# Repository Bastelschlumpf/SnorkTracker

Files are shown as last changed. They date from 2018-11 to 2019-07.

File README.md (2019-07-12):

## SnorkTracker
   **GPS IoT tracker board for scanning gps and environment information and sending them to an MQTT server via GPRS.**
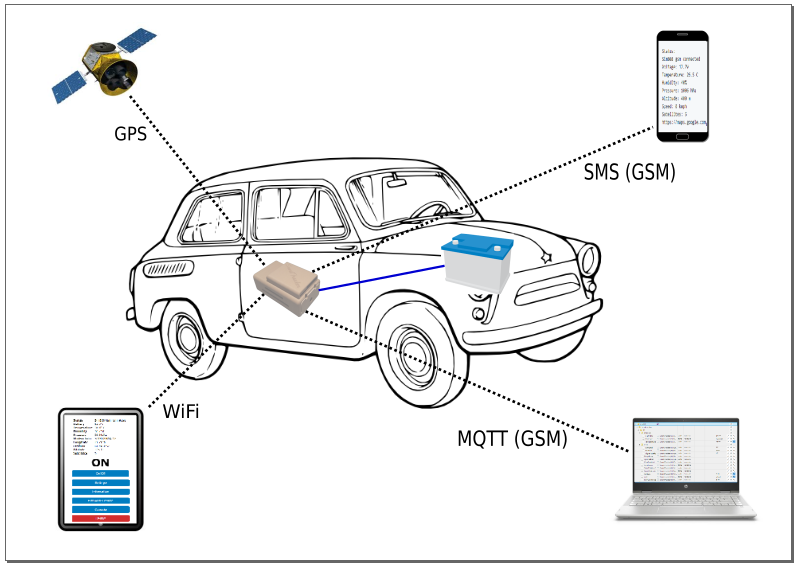
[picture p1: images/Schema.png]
SnorkTracker Schema
   

   **IoBroker map of the collected SnorkTracker sample.  
   (see https://github.com/Bastelschlumpf/SnorkView)**
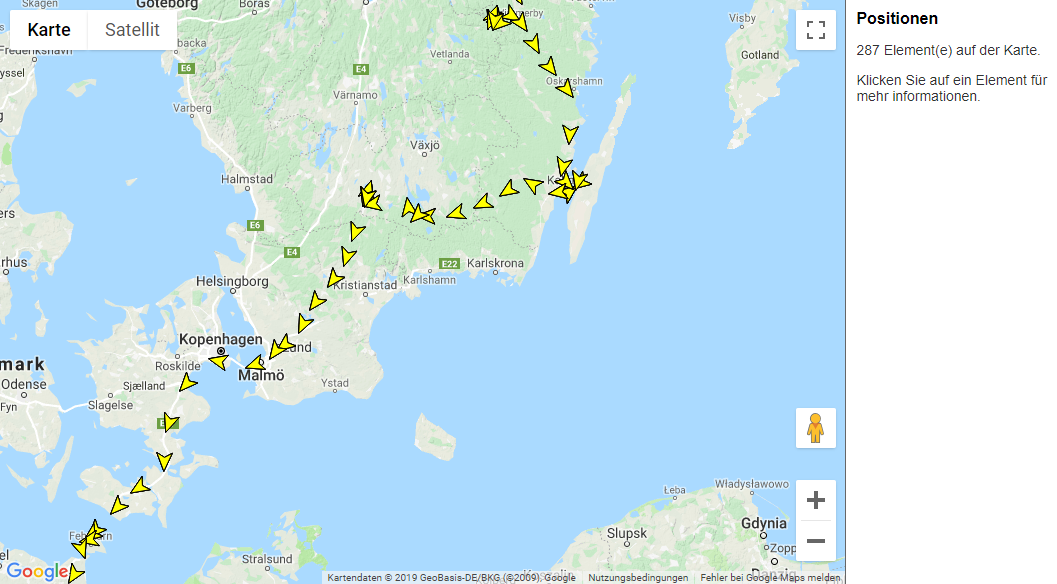
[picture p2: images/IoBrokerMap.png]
SnorkTracker View SnorkTracker Schema
   

   **The hardware**  
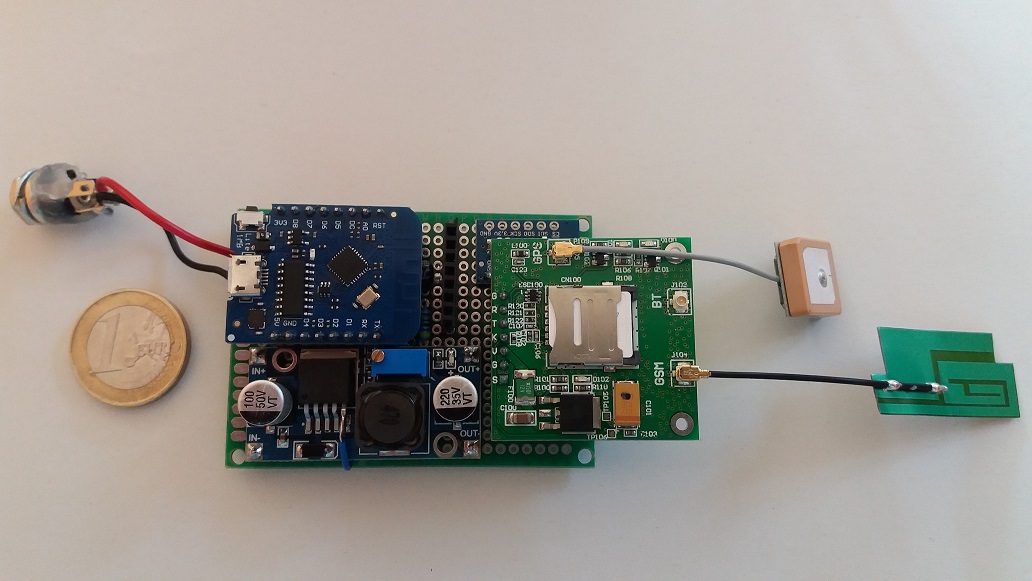
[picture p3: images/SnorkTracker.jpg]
SnorkTracker
   

   **The housing**  
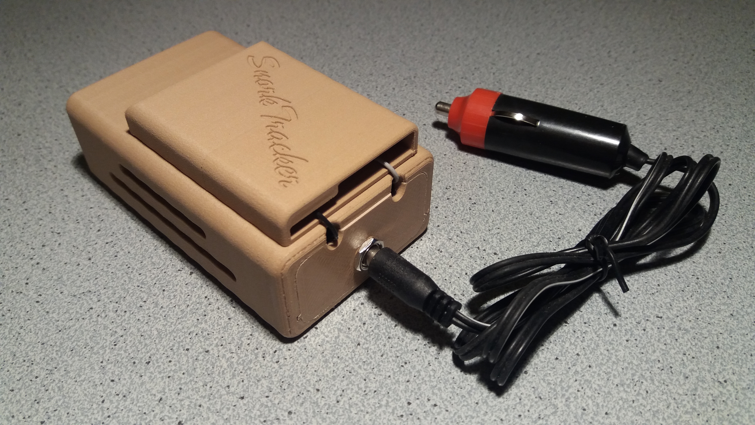
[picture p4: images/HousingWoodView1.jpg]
   

   **The web-interface**  
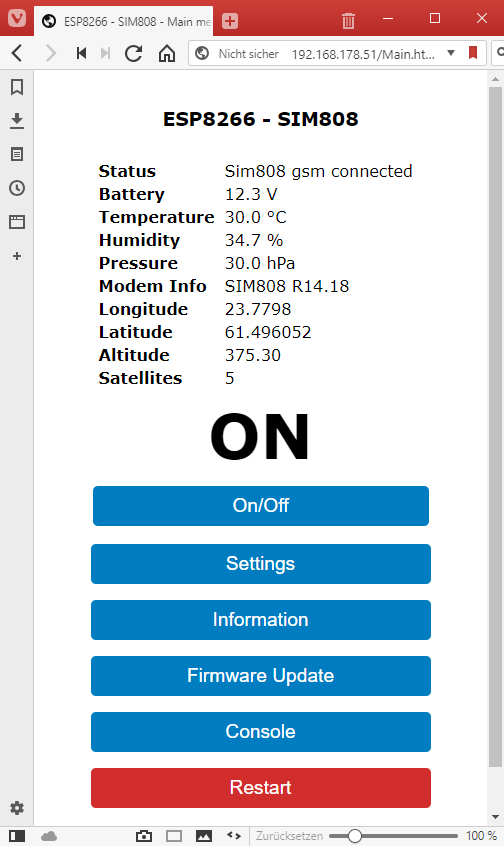
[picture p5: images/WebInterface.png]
Web interface
   

### Description
   The goal of this board is to have an easy-to-use, configurable GPS tracker that passes its data to an MQTT server. 
   It should also be able to scan other environmental data and operate on a 12V power supply with low power consumption 
   over a long period of time.

   The main components of the systems are:
   * A 'Wemos D1 mini lite' to run the software.
   * A BK-808 v2 (SIM808) GPS/GPRS module to communicate with an MQTT server and to send/receive SMS.
   * A BME280 module to scan environmental data.
   * An LM2596 DC-DC converter to supply the GPS/GPRS board.
   * An MCP1703 for the 3.3V Wemos power supply.

   To interact with the board it has an easy-to-use browser interface to show the
   scanned values, configure the system or to debug at runtime via console. 
   It can connect to an existing WiFi or function as an access point.

   The board has a voltage divider to measure the power supply voltage and
   a BME280 sensor to read temperature, humidity and air pressure.

   The module operates with a supply voltage of approx. 6V to 16V. Perfect for a car battery.

   For power saving the supply voltage can be used to decide if the battery is charging or not
   and so the system can be configured to go into deep sleep mode which uses only ~0.3mA.

   With the GSM chip, the system can receive SMS commands to set default values or send current
   information such as GPS or temperature.

   The system estimates the current power consumption in mAh in energy saving mode and when the sim module is on. 

   You can also use the software on a esp8266 chip like the wemos d1 for having a serial console over HTTP if you connect
   to the D5 and D6 pin.

### Disclaimer
   I don't take any responsibility nor liability for using this software nor for the 
   installation or any tips, advice, videos, etc. given by any member of this site or any related site.

### License
   This program is licensed under GPL-3.0

### Source Code
   The easiest way to understand what the program does is to navigate by the main source modules via the Arduino IDE or 
   to explore the source code via
   [**DoxyGen generated documentation**](https://bastelschlumpf.github.io/SnorkTracker).  
   You can update the DoxyGen generated documentation by installing Doxygen (from http://www.doxygen.org) on your machine 
   and run the DoxyGen generation batch **Doxygen.bat** from the main folder.

### User manual of the web interface
  * [Overview of the system settings](docs/Seettings.md)
  * [Switch on or off the system](docs/SwitchOnOff.md)
  * [Using the sms interface](docs/SMS.md)
  * [Display system information](docs/Information.md)
  * [Working with the console](docs/Console.md)
  * [Firmware Update 'over the air'](docs/OTA.md)
  * [Restart the system](docs/Restart.md)

### Prerequisites
   * Arduino IDE
   * ESP8266 Board software
   * ESP8266 file-system up-loader
   * **SnorkTracker** software
   * Parts from the part-list
   * Micro-USB cable
   * Soldering iron kit
   * Multimeter
   * Electronics tools

### Setup Arduino Environment
   * Download Arduino IDE from  
     https://www.arduino.cc/en/Main/Software  
     and follow the installation instructions.
   * Install ESP8266 board software
      *  In Arduino IDE set 'File | Preferences' to Boards Manager URL 
         http://arduino.esp8266.com/stable/package_esp8266com_index.json  
      * Open 'Tools | Board... | Boards Manager...' 
        and search for 'esp8266' and install the software package
   * Install the ESP8266 file-system up-loader from  
      https://github.com/esp8266/arduino-esp8266fs-plugin  
      and follow the installation instructions.
   * Download **SnorkTracker** software by clone or download.
   * Copy the content of the snorktracker/libraries directory to the Arduino installation libraries directory.
     For example c:/Program Files (x86)/Arduino/libraries/
   * Configure Arduino IDE
     * From 'Tools | Boards' choose 'LOLIN(WEMOS) D1 mini Lite'
     * Change 'Tools | Flash Size' to '1M (64k SPIFFS)'
     * Change 'Tools | IwIP variant' to 'v2 Higher Bandwidth' 

### Circuit
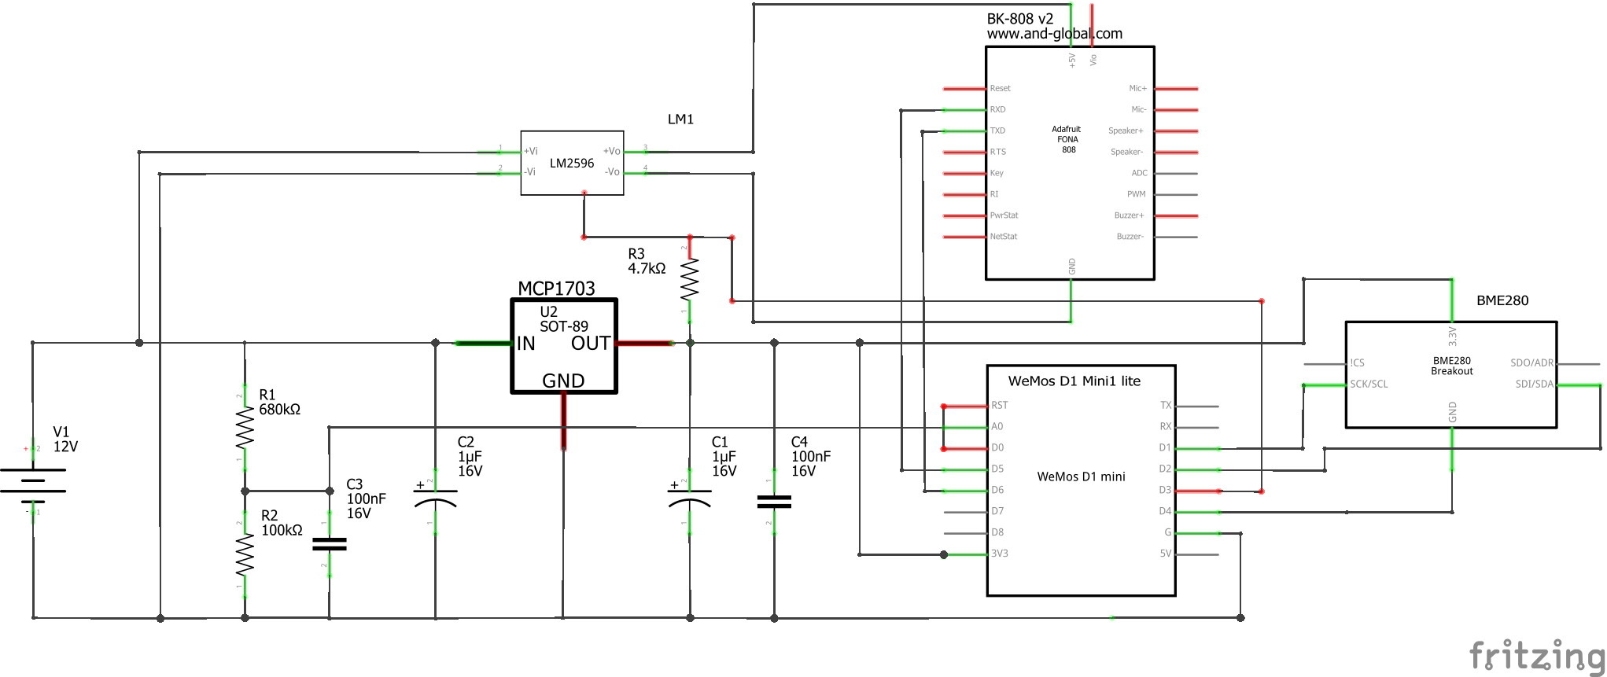
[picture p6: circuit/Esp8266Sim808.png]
   

### Housing
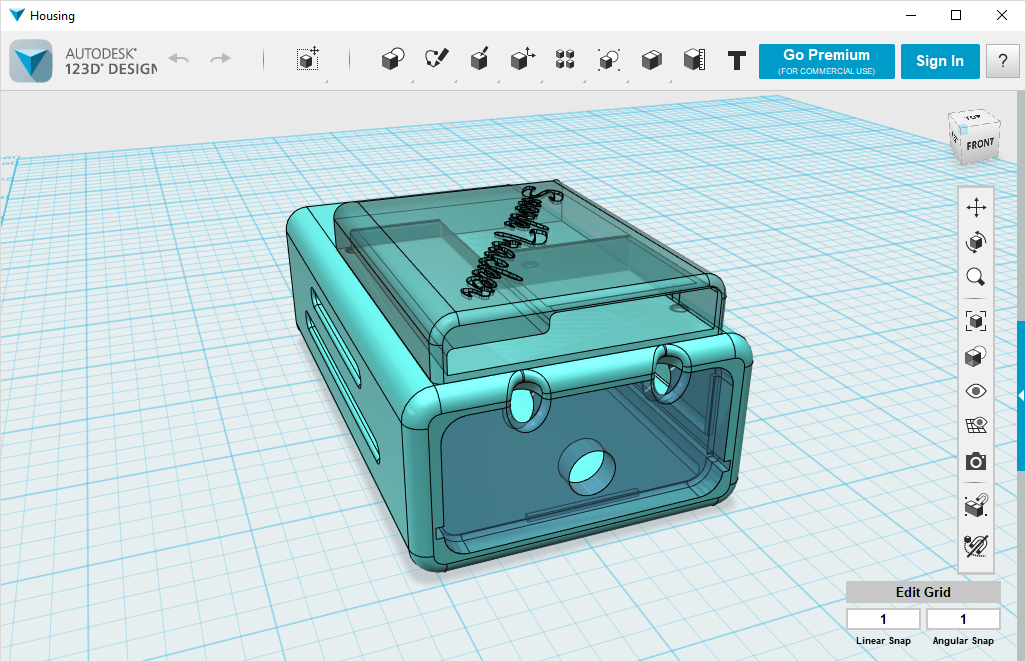
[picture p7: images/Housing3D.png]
Housing Prototype Housing 3D Model
   
  * [See 3D Housing](docs/Housing.md)

### Assemble the Components
   * Take the Breadboard and the other items from the part-list.  
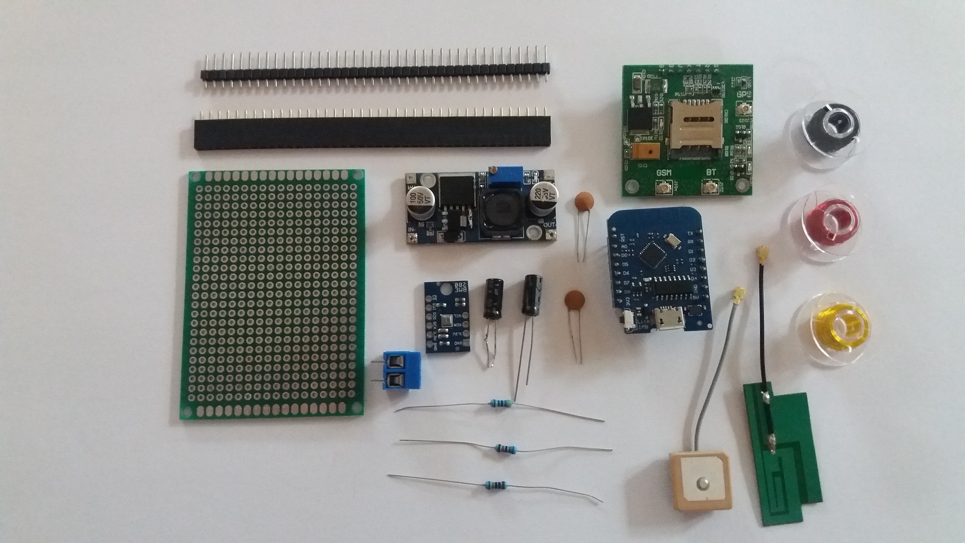
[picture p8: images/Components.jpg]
Components
     
   * First of all unsolder the (ON/OFF) pin 5 from the DC-DC module, bend it up and
     solder a line to it. After that put 4 spacers under the DC-DC module and solder it
     to the breadboard. Check that the bottom of the LM2596 module is not in contact with the board.
     See  
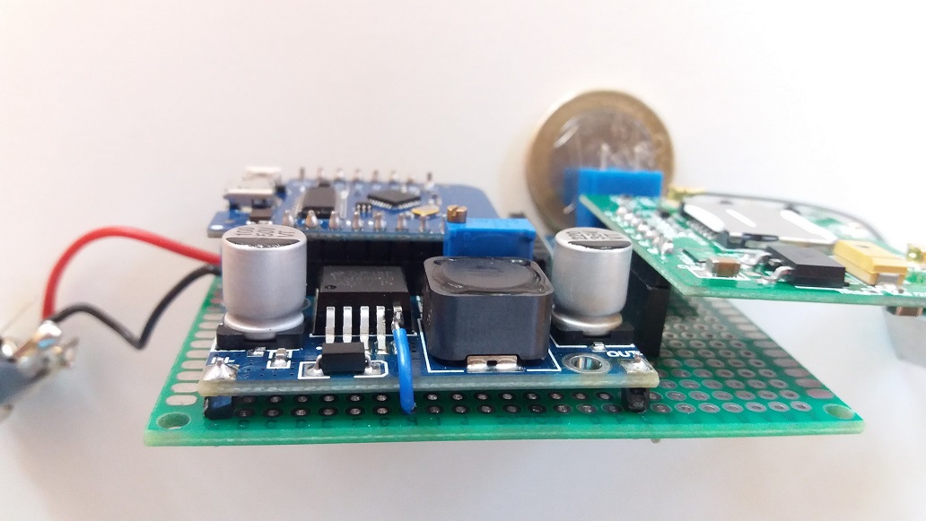
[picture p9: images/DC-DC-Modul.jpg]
DC-DC module
     
   * Place the other parts from the part-list on the breadboard and solder it as shown. 
     Pay attention to the polarity of the capacitors!
     Split the header connector to the length that is needed and solder it. 
     A header connector is needed because flashing of the Wemos module often does not work 
     if it is still connected to the board.
     Check if the Wemos and SIM808 module has enough space and fits into the pins.  
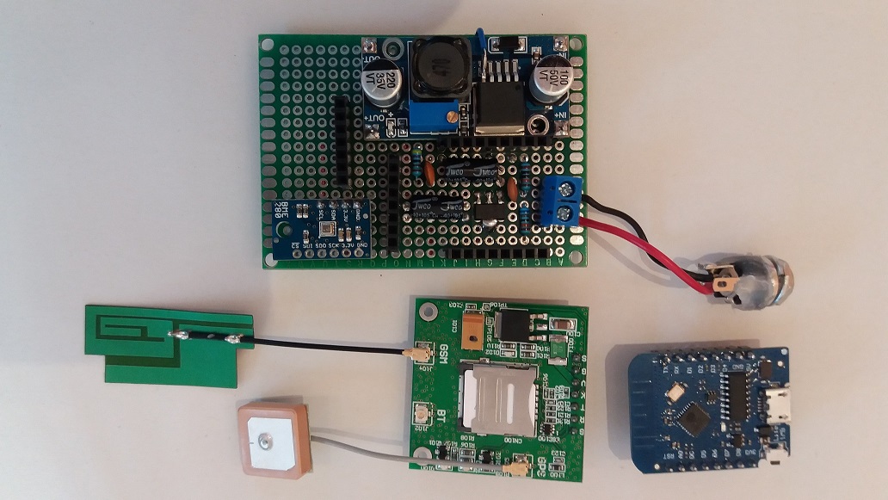
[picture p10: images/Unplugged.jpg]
Unplugged
     
   * Connect all the pins of the parts as seen on the circuit image with wires.  
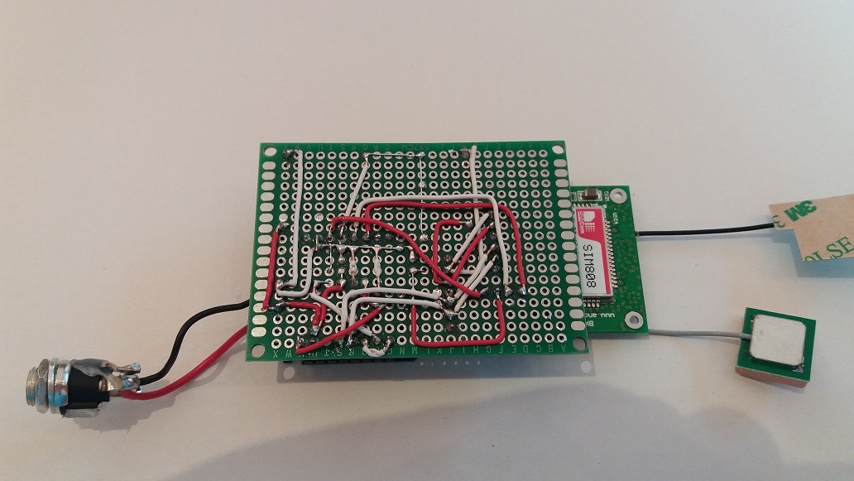
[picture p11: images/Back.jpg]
Back
     
   * The final board could look like this  
     Snorktracker board
   * Check all the wiring with a multimeter. Also against short-circuit.

### Setup the LM2596 voltage and install the software
   * The first step we have to do is to set the right 5V for the SIM808 module.
     * For that unplug the Wemos and the SIM808 module.
     * Connect a 12 power supply to the screw connector. Make sure + and - are correct!
     * Switch on the LM2596 module by connecting the unsoldered pin 5 to ground. 
     * Now, connect the multimeter to the output pins of the DC-DC module and screw on
        the module resistor until the multimeter shows exactly 5.0V on the two out-pins.
   * Check the pins on the female header connector for the right voltage.
     * Check the 3.3V on the corresponding WEMOS pin.
     * Check the 5.0V pin of the SIM808 module connector pin.
     * Check the 3.3V on the BME280 module. Be aware that the ground pin is connected to
        the Wemos module and still open.
   * Now its time to flash the software to the Wemos module.
     * Unplug the Wemos module (if plugged) and connect it with the USB cable to your computer.
       After connecting via usb you should be able to select the arduino port under 'Tools | Port | ...'.
     * Open the tracker.ino file in the tracker folder and check the Arduino environment settings.
     * Upload the SPIFFS files with the 'Tools | ESP8266 Sketch data upload' menu.
       The SPIFFS files (htmls, styles and javascripts) are taken from the data subdirectory.
     * After that go to the *Config.h* file of the project and enter the right configuration values.
     * Now we can flash the program to the Wemos chip by clicking 'Sketch | upload'
     * Unplug and plug again the Wemos module to the usb cable and start immediately the serial monitor 
       of the Arduino IDE 'Tools | Serial monitor'.
     * If everything is correct you can see an access-point in the WiFi of your computer and you can connect 
       to the browser interface by calling the ip in your browser.
       The software works in a captive way, so you can enter a dummy (not https) url and the system should redirect you 
       to the web interface. For example http://dummy.com
       If this does not work find out the new ip via your WiFi router interface.
   * If the software works fine on the usb cable then you can plug the wemos into the board and connect a power supply.
     Check again the connectivity.

### Function
   * The software in the Wemos module creates a web-server in station and/or in access-point mode.
   * The analog input of the wemos is connected to the middle of the two voltage divider resistors.
     So it can read the power supply voltage of the system (for example the car battery voltage).
   * The software can be configured to recognize a charging or discharging car battery to switch on or off the 
     submodules. With my car this was:
     * 11.8 Volt if the car was switched off for more than a day.
     * 14.2 Volt if the engine is running.
     * 13.3 Volt after switching off the engine.
   * A BME280 sensor is connected to the 3.3V power and can be switched on by setting the D4 pin of the wemos chip
     to ground. This is done only from time to time to save energy.
   * There is an LM2596 DC-DC module on the board which can be switched on by a '-' signal to the pin 5 of the LM2596.
     Behind the DC-DC module there is a SIM808 module with GPS/GPRS/GSM functionality. So the Wemos can switch on/off 
     the SIM808 chip to save energy.
   * The Wemos chip can communicate with the SIM808 module via RX and TX signal and AT commands.
   * Via the GPRS module it can send the scanned data to a MQTT server and can communicate via SMS to a phone.

### Part-list
|Label |Part Type |Properties |
|---|---|---|
|Breadboard |Double sided PCB board |24 x 18 holes |
|Power connector |Mount screw connector |2 pins |
|Header connector |Female header connector  |3 x 9 pins |
|wire |colored breadboard wire  |i.e. 0.14 mm2 |
|12V Plug |Cigarette Lighter Power  |12V To 5.5 x 2.1mm|
|Panel Jack |Jack Socket Female |5.5 x 2.1mm |
|V1 |VC Power |6V - 16V |
|WeMos D1 Mini lite |WeMos D1 Mini lite |ESP8295 |
|BK-808v2 |BK-808 v2 |www.and-global.com|
|GPS Antenna |Embedded GPS Antenna |uFL connector |
|GSM Antenna |Embedded GSM Antenna |uFL connector |
|SIM card |SIM card for sms/data |with deposit |
|BME280 |BME280 |3.3V |
|LM1 |LM2596 |adjustable module |
|U2 |Voltage Regulator 3.3V |MCP1703T-3302E |
|C1 |Electrolytic Capacitor |1uF (16V) |
|C2 |Electrolytic Capacitor |1uF (16V) |
|C3 |Ceramic Capacitor |100 nF (16V) |
|C4 |Ceramic Capacitor |100 nF (16V) |
|R1 |Resistor |680 kOhm |
|R2 |Resistor |100 kOhm |
|R3 |Resistor |4.7 kOhm |

### Shopping list
Here are some sample shopping items. Please check the details if everything is correct.

|Label |Price |Sample URL |
|---|---|---|
|Breadboard set |13$ | https://www.amazon.com/Paxcoo-Double-Prototype-Connector-Terminal/dp/B07C3TC68Z |
|wire |13$ | https://www.amazon.com/StrivedayTM-Flexible-Silicone-electronic-electrics/dp/B01KQ2JN |
|12V Plug |2$ | https://www.amazon.com/Zerone-Cigarette-Lighter-Supply-Adapter/dp/B07DWRVBLF/ref=sr_1_1 |
|Panel Jack |2$ | https://www.amazon.com/Abicial-5-5mm-Socket-Female-Connector/dp/B07J9WRC2Z/ref=sr_1_2 |
|WeMos D1 Mini lite |10$ 2 pcs  | https://www.amazon.com/Aideepen-Development-ESP8285-V1-0-0-Internet/dp/B07BGW7QG |
|BK-808v2 |22$ | https://www.amazon.com/Breakout-Quad-band-GSMGPRS-Integrated-GPSBluetooth/dp/B0748DGCRN |
|GPS Antenna |9$ | https://www.amazon.com/CIROCOMM-Antenna-Ceramic-25x25x2mm-Geekstory/dp/B078Y2WNY6 |
|GSM Antenna |6$ | http://www.amazon.com/CIROCOMM-Antenna-Ceramic-25x25x2mm-Geekstory/dp/B078Y2WNY6 |
|BME280 |10$ | https://www.amazon.com/Breakout-Temperature-Humidity-Barometric-Pressure/dp/B01LETIESU |
|LM1 |7$ 2pcs | https://www.amazon.com/DZS-Elec-Adjustable-Electronic-Stabilizer/dp/B06XRN7NFQ |
|U2 |1$ | https://www.mouser.ch/ProductDetail/Microchip-Technology/MCP1703T-3302E-DB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 |
|C1, C2 |10$ set | https://www.amazon.com/WINGONEER-Electrolytic-Capacitors-Assorted-Assortment/dp/B0734T3GJ9 |
|C3, C4 |13$ set | https://www.amazon.com/Terrans-Monolithic-Multilayer-Capacitors-Non-Polarized/dp/B07B91SW4Y |
|R1, R2, R3 |10$ set | https://www.amazon.com/Resistor-Assortment-Kit-Thermistor-Photoresistor/dp/B0792M83JH |

Some of the items are sets for further projects. You can also buy cheaper single items.
The material price should be between **50$** and **100$**.

### Thanks
   * https://www.arduino.cc
     *Thanks to the Arduino community with all its incredible possibilities and support.** 
   * https://github.com/arendst/Sonoff-Tasmota
     *Thanks to Theo Arends for his great home automation software project with all the detailed esp functionality.*
   * http://fritzing.org/home
     *Thanks to the fritzing team for this very intuitive usable software.* 
     I could create my circuit in Fritzing with only a half day.
   * https://marketplace.visualstudio.com/items?itemName=MadsKristensen.MarkdownEditor
     *Thanks to Mads Kristensen for his helpful Visual Studio MarkDown PlugIn.**
   * **And a special thanks goes to my brother for all the hours he spent helping me with the electronic circuit.**

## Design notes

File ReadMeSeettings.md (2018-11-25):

## Overview of the system settings

### Connect to the Web Interface
The easiest method is when the module automatically logs into your Wifi network. 
To do this you change the two defines **WIFI_SID** and **WIFI_PW** in Config.h before compiling.
If you supply then the system with power, it starts the integrated web server and logs into 
your WiFi network. You can use your router software to search for the new SnorkTracker IP.
You can then open a web browser and enter this new ip as http://xxx.xxx.xxx.xxx
Attention: The system does not support https yet so it only works if the URL starts with **http:**

If you have problems finding out the new IP, you can also simply search for the new access point 
called **SnorkTracker** in your WiFi settings and then connect to it.
If you have connected to this access point you can now connect with a browser. 
Since the system works with a captive portal and redirects all unknown urls to its own, 
it is sufficient if you enter a random http: - url.  
e.g. http://Dummy.html  
Make sure you use http and not https.

## Configure the details
If you now have access to the web server interface you can configure all the details via the 
**Settings** page.

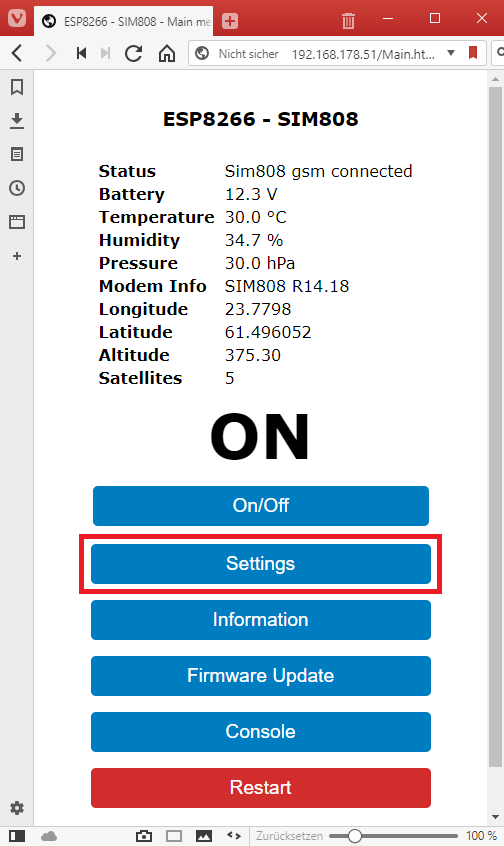
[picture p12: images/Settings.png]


All other settings are now described in detail below.

Hint: All Interval settings can be entered as '[days] hours:minutes:seconds' or just 'seconds'.

### WiFi Settings
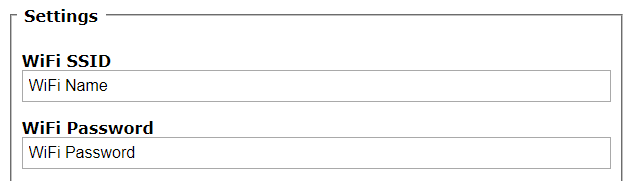
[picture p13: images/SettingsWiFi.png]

If not configured via the **Config.h** file you can change here the access point name and 
password to your WiFi.

### GPRS Settings


Be sure that you have inserted a valid SIM card with a valid contract into the SIM card slot
of the SIM808. Note that the system connects without a password.
So the easiest way to check if the system works without a password and to check if it can connect
to a gprs network is to put it into a mobile phone and check on start for password query and 
browsing functionality.

To connect to the Internet different gprs provider use different gprs access point names.
For example, sunrise uses the access point name 'internet' and swisscom the name 'gprs.swisscom.ch'.
Search the Internet for the access point name of your provider.

### Enable debugging


The system has possibility to put more detailed information to the console window.
If you want to know i.e. the detailed communication between the esp8266 and the sim808 module
you can switch on here the display of this information.
For performance reason it is better to switch off this if it is not needed.

### Enable environment sensor


The system is connected to a BME280 sensor. This sensor can scan the temperature, humidity and
the pressure of its environment.
With this settings you can control the interval of the scan. These environment values doe not change so 
often so it is enough if this interval is set to a bigger value like 1 minute or bigger. 

### SMS Settings
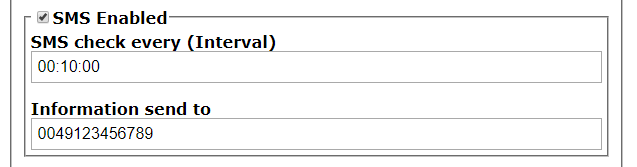
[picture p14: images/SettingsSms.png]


If the system is switched on and it has a valid gprs connection details of it can be controlled 
via incoming sms.
Here you can set the interval of this sms check.

### GPS Settings


If the system is switched on you can also switch on the gps check functionality and the
gps check interval here.
Remember that it can take up to a minute for the sim808 module to receive a valid gps signal.
If you configure a gps check interval below this the system waits until it has a valid gps value.

### MQTT Settings
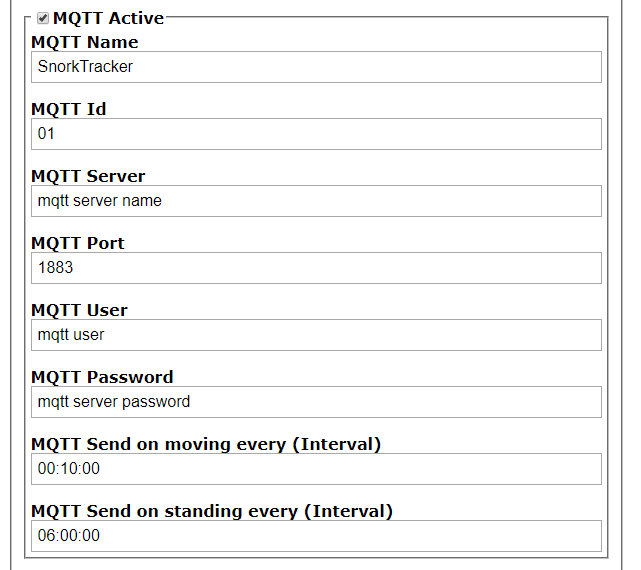
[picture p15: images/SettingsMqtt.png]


With this settings part you can configure the mqtt connection to your mqtt server.
If the system has a valid mqtt server connection it sends only the information that are valid
at this moment. So, for example if you switched off the gps then this information could not be 
send to your server.
If you have switched on the gps sending than you can additionally configure here how often the gps 
values should be send while your system is moving and how often if the system stands fix on one place.

Here is a screen shot of a mqtt server result in  
**ioBroker** software. See http://iobroker.net

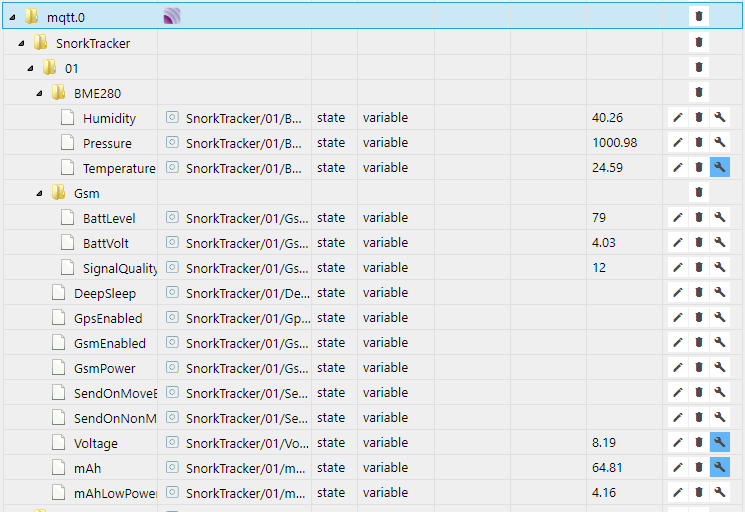
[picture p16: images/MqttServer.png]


Remember the system works with HTTP and not with HTTPS. So be sure you can connect with this
protocol to your MQTT server.

### Power Save Setting
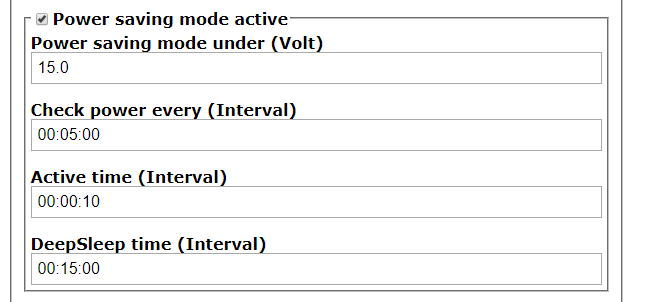
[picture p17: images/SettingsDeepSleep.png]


If you connect the system to a battery it is important that you don't use to much power consumption.
Here you can configure that the system can detect if your battery is powered via a generator or not.
Make some tests how much voltage the battery has when charging and when not charging.
Then set a value between the two values here so the system can sleep if not charging.
It is better to set the active time to low value because the system waits with the sleep mode
if all the needed operations (gps, mqtt, sms) are done.

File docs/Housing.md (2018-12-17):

### Housing (Prototype)

Here are a prototype made of cardboard.

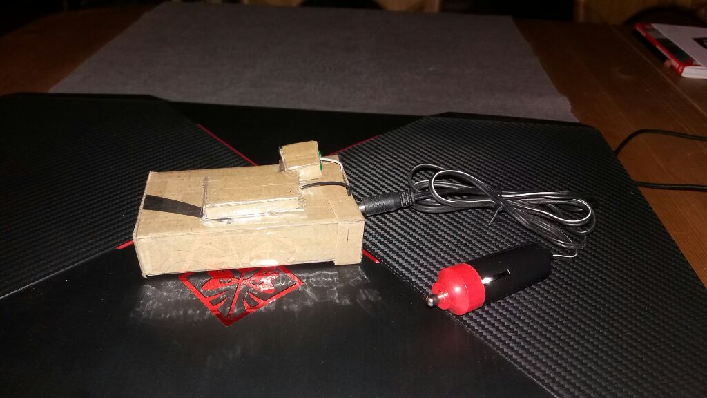
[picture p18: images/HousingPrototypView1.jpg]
Prototype View 1
   

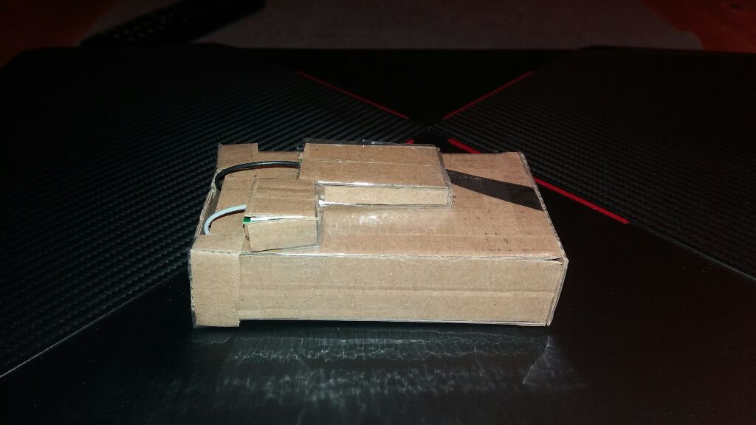
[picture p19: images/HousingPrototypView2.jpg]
Prototype View 2
   

And here the AutoDesk 123D Design model for 3D printing.

You will find also the .stl files in the housing folder.

   Prototype 3D Model

At the end I printed the Snorktracker with this great 3D printer in 10 hours.

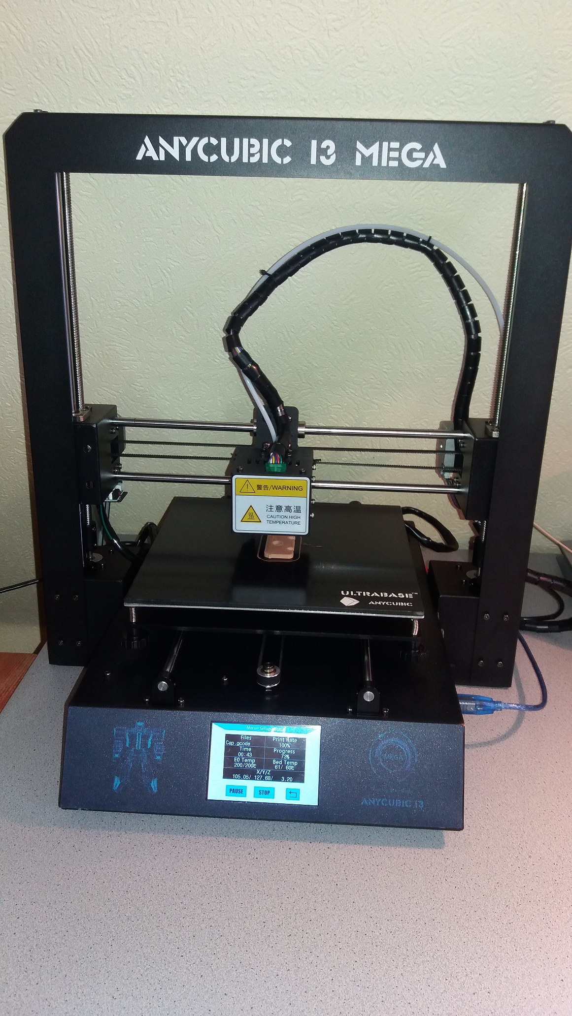
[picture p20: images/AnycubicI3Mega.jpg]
Anycubic I3 mega
   

Here the version in black

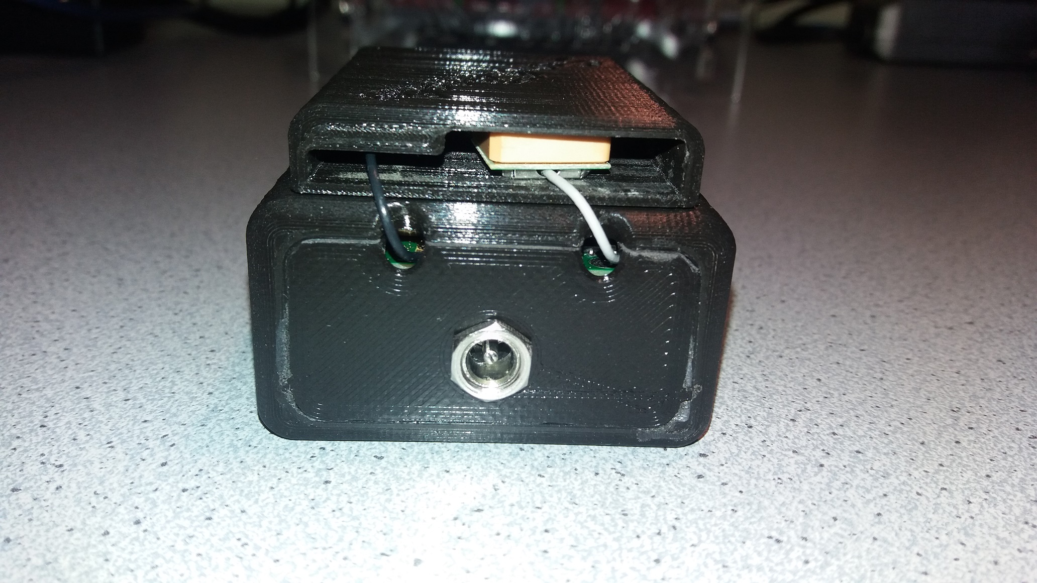
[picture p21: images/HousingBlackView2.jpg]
SnorkTracker housing black front
   

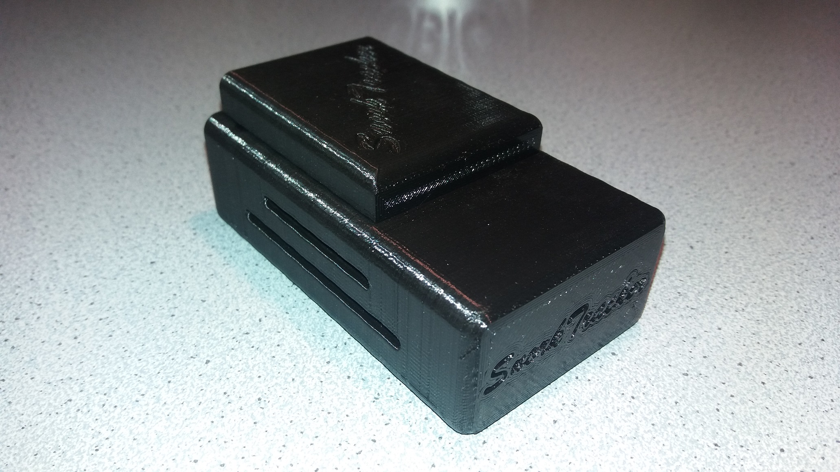
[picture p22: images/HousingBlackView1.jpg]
SnorkTracker housing black side
   

And here the version in PLA wood 

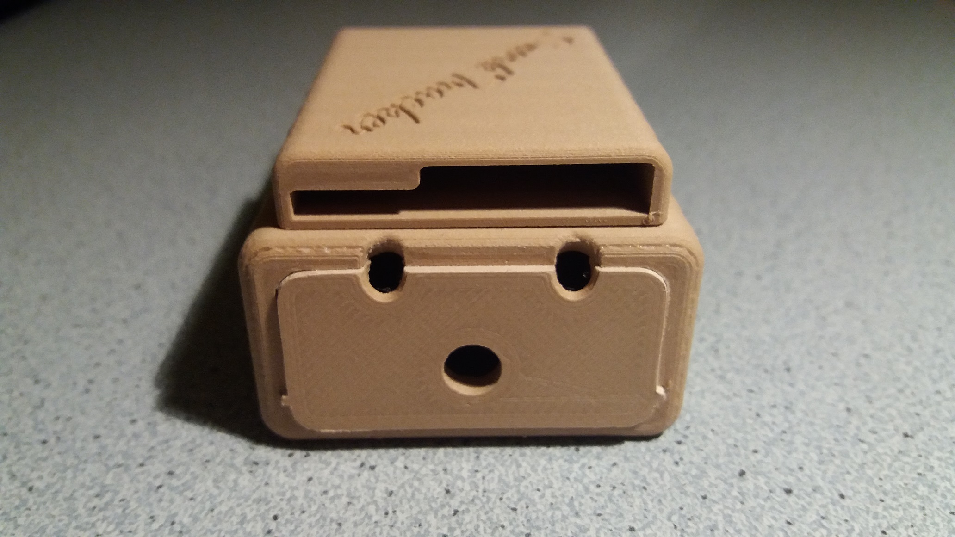
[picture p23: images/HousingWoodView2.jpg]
SnorkTracker housing wood front
   

   SnorkTracker housing wood side

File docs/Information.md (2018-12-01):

### Display system information
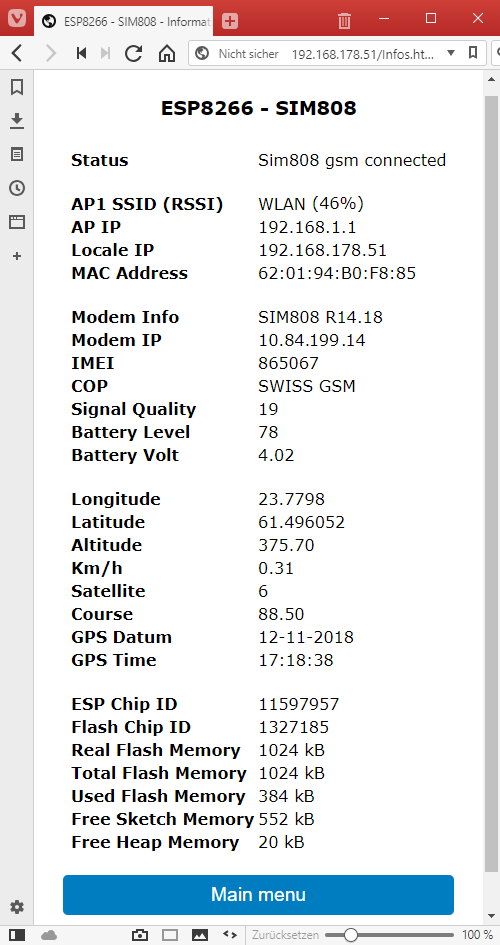
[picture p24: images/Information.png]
Information Page
   

Note: Some of the informations may be not visible if the function is not enabled.

| Name | Sample | Description |
|---|---|---|
|Status| Sim808 gsm connected |The current status of the wemos - sim808|
|AP1 SSID (RSSI)|WLAN (46%)|The name of the connected Wi-Fi access point and the quality of the signal.|
|Locale IP| 192.168.178.51 |The current IP of the Tracker|
| | | |
|Modem Info|SIM808 R14.18|The response of the SIM808 modem-info AT request|
|Modem IP|10.84.199.14|The IP of the gsm modul when connected to the INTERNET|
|IMEI|865067|The IMEI of your SIM card|
|COP|SWISS GSM|Your GSM operator|
|Signal Quality|19|The quality of the current signal|
|Battery Level|78|The quality of the power supply to the sim808 modul. This can be ignored because it should be fix with the DC-DC modul.|
|Battery Volt|4.02|The Volt of the power supply to the sim808 modul. This can be ignored because it should be fix with the DC-DC modul.|
| | | |
|Longitude|23.7798|The longitude value of your gps position.|
|Latitude|61.496052|The latitude value of your current gps position.|
|Altitude|375.70|The current altitude in meter|
|Km/h|0.31|The current speed in km/h|
|Satellites|6|The number of fix satellites for the current gps position|
|Course|88.50|The course in degrees|
|GPS Datum|12-11-2018|The datum from the gps satellites in UTC|
|GPS Time|17:18:38|The time from the gps satellites in UTC|
| | | |
|ESP Chip ID|11597957|The internal ID of the esp chip|
|Flash Chip ID|1327185|The internal ID of the ESP flash memory chip|
|Real Flash Memory|1024 kB|The actual chip size based on the flash id|
|Total Flash Memory|1024 kB|The size of the flash as set by the compiler|
|Used flash Memory|384 kB|The sketch size in memory|
|Free Sketch Memory|552 kB|The free sketch memory|
|Free Heap Memory|20 kB|Free heap memory for variables|

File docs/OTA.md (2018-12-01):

### Firmware Update 'over the air'

OTA (Over the Air) update is the process of loading the firmware into the Modul via a Wi-Fi connection and 
not via a serial port. This functionality can be very useful if the device is already installed or 
difficult to access.

For information about OTA, simply search the Internet for the keywords ESP8266 and OTA or take a look at the page:

 [**OTA Update ESP8266**](http://esp8266.github.io/Arduino/versions/2.0.0/doc/ota_updates/ota_updates.html)

Start the OTA functionality by pressing the 'Firmware update' button and answering the security question with Yes. 

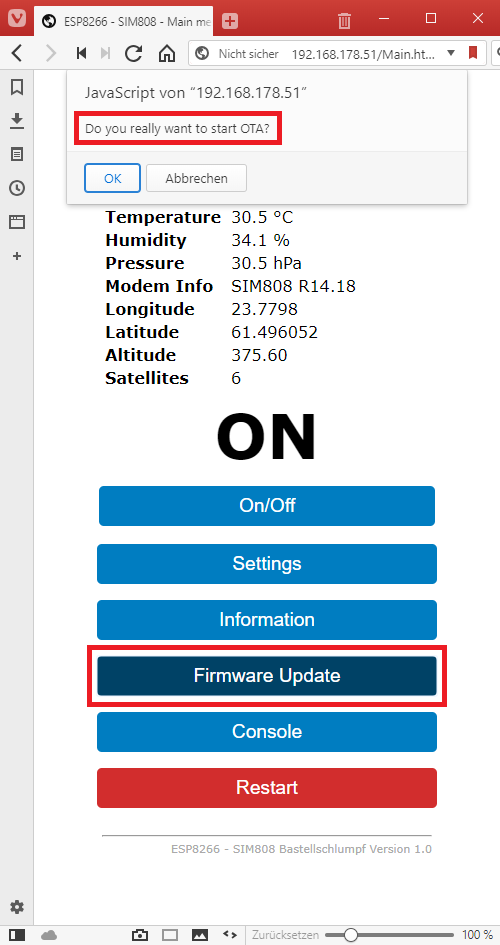
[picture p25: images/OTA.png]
OTA
   

If the OTA function could be started successfully, the following display appears:

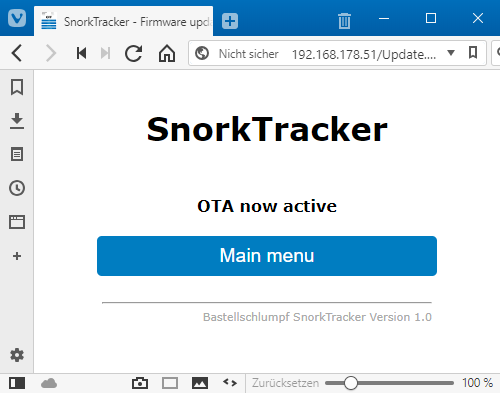
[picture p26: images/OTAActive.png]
OTA Active
   

And in your Arduino environment the OTA connection should be displayed under 'Port'. If this is not the case, 
sometimes restarting the Arduino IDE will help.

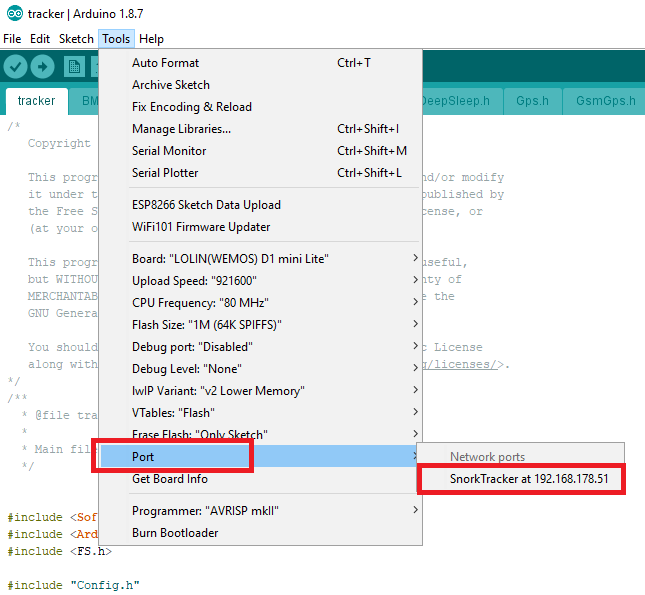
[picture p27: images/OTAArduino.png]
OTA Arduino
   

**Note:** Unfortunately this only works to update the Snorktracker software and not to transfer the SPIFFS web server files.

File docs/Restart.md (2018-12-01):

### Restart the system

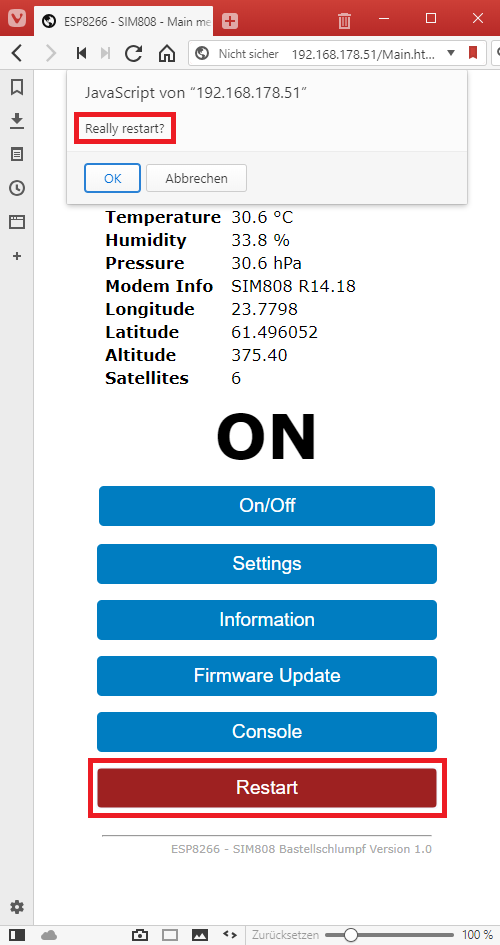
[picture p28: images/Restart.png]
System restart
   

Should it be necessary that you want to restart the system, you can do so via the Restart button.

Afterwards the system displays the current IP in a MessageBox and asks for confirmation.

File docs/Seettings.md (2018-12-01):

## Overview of the system settings

### Connect to the Web Interface
The easiest method is when the module automatically logs into your Wifi network. 
To do this you change the two defines **WIFI_SID** and **WIFI_PW** in Config.h before compiling.
If you supply then the system with power, it starts the integrated web server and logs into 
your WiFi network. You can use your router software to search for the new SnorkTracker IP.
You can then open a web browser and enter this new ip as http://xxx.xxx.xxx.xxx
Attention: The system does not support https yet so it only works if the URL starts with **http:**

If you have problems finding out the new IP, you can also simply search for the new access point 
called **SnorkTracker** in your WiFi settings and then connect to it.
If you have connected to this access point you can now connect with a browser. 
Since the system works with a captive portal and redirects all unknown urls to its own, 
it is sufficient if you enter a random http: - url.  
e.g. http://Dummy.html  
Make sure you use http and not https.

## Configure the details
If you now have access to the web server interface you can configure all the details via the 
**Settings** page.

Settings overview

All other settings are now described in detail below.

Hint: All Interval settings can be entered as '[days] hours:minutes:seconds' or just 'seconds'.

### WiFi Settings
Wi-Fi Settings
If not configured via the **Config.h** file you can change here the access point name and 
password to your WiFi.

### GPRS Settings
GPRS Settings

Be sure that you have inserted a valid SIM card with a valid contract into the SIM card slot
of the SIM808. Note that the system connects without a password.
So the easiest way to check if the system works without a password and to check if it can connect
to a GPRS network is to put it into a mobile phone and check on start for password query and 
browsing functionality.

To connect to the Internet different gprs provider use different gprs access point names.
For example, sunrise uses the access point name 'INTERNET' and swisscom the name 'gprs.swisscom.ch'.
Search the Internet for the access point name of your provider.

### Enable debugging
Debug Settings

The system has possibility to put more detailed information to the console window.
If you want to know i.e. the detailed communication between the esp8266 and the sim808 module
you can switch on here the display of this information.
For performance reason it is better to switch off this if it is not needed.

### Enable environment sensor
BME280 Settings

The system is connected to a BME280 sensor. This sensor can scan the temperature, humidity and
the pressure of its environment.
With this settings you can control the interval of the scan. These environment values doe not change so 
often so it is enough if this interval is set to a bigger value like 1 minute or bigger. 

### SMS Settings
SMS Settings

If the system is switched on and it has a valid gprs connection details of it can be controlled 
via incoming sms.
Here you can set the interval of this sms check.

### GPS Settings
GPS Settings

If the system is switched on you can also switch on the gps check functionality and the
gps check interval here.
Remember that it can take up to a minute for the sim808 module to receive a valid gps signal.
If you configure a gps check interval below this the system waits until it has a valid gps value.

### MQTT Settings
MQTT Settings

With this settings part you can configure the mqtt connection to your mqtt server.
If the system has a valid mqtt server connection it sends only the information that are valid
at this moment. So, for example if you switched off the gps then this information could not be 
send to your server.
If you have switched on the gps sending than you can additionally configure here how often the gps 
values should be send while your system is moving and how often if the system stands fix on one place.

Here is a screen shot of a mqtt server result in  
**ioBroker** software. See http://iobroker.net

MQTT Server Settings

Remember the system works with HTTP and not with HTTPS. So be sure you can connect with this
protocol to your MQTT server.

### Power Save Setting
Deep Sleep Settings

If you connect the system to a battery it is important that you don't use to much power consumption.
Here you can configure that the system can detect if your battery is powered via a generator or not.
Make some tests how much voltage the battery has when charging and when not charging.
Then set a value between the two values here so the system can sleep if not charging.
It is better to set the active time to low value because the system waits with the sleep mode
if all the needed operations (gps, mqtt, sms) are done.

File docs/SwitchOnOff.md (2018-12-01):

### Switch on/off

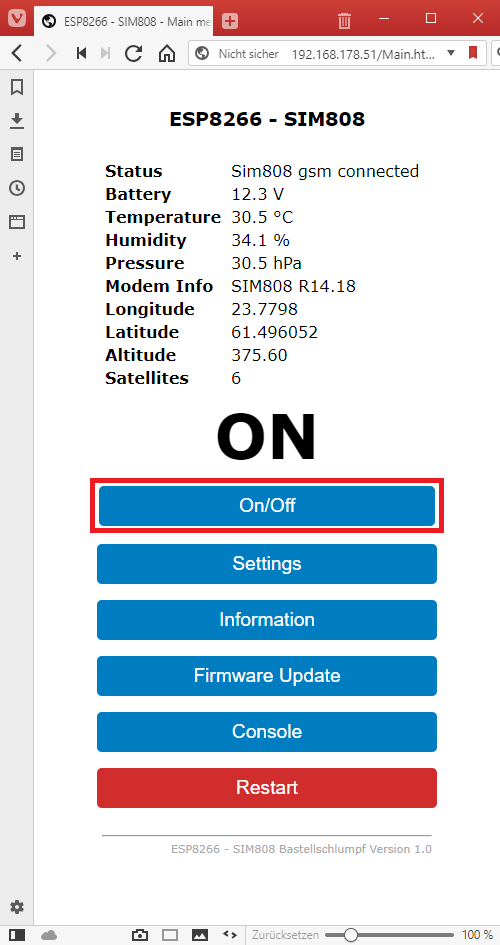
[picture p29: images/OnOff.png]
Switch on off
   

You can switch on or switch off the system with the first button on the main page.

On/Off only affects GPS, SMS and MQTT functions (if enabled).
The ambient sensor independently checks the temperature, air pressure and humidity 
after the set time interval.

When switching on the GSM function it may happen that the system does not react 
for a short time. The simplest way to monitor that no errors occur is to switch 
to the console view immediately after switching on and display the communication.

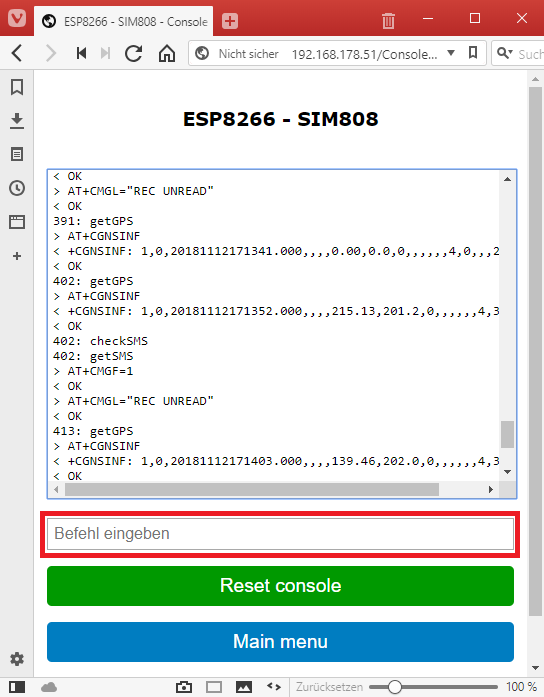
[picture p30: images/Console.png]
Console page


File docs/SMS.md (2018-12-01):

### Using the sms interface

The Snorktracker can receive and send SMS using the GSM module. 
The SMS function must be activated under Settings and 
and the correct answer phone number must be entered.

The following commands are implemented:
Note: All commands are case insensitive.

#### Switch On or off

You can switch the system on or off if you send a
**on** or **off** sms to the sim-card phone number.
If the system accepted the command it sends a 

    **on -> OK** 
or 

    **off -> OK** 
back.

#### Send back the status of the system

You can query the system for the main information if you send
**status** to the Modul phone number.
The system should then response with the following result:

    Status: 
    Sim808 gsm connected
    Voltage: 12.2V
    Temperature: 26.5 C
    Humidity: 40%
    Pressure: 1006 hPa
    Altitude: 400 m
    Speed: 0 kmph
    Satellites: 5
    https://maps.google.com/maps?q=61.496052,23.7798"

#### Change the 'Power save mode'

If your system is in deep sleep it could be very tricky to catch the time when the system awakened.
It is much easier to send a 'popwer save mode off' via sms to the module.
To do that you have to send a **psm:off** to the system phone number and wait for a successful response

    **psm:off -> OK** 

Afterwards you can switch on the power save mode via the web interface or by sending a 
**psm** sms.

    **psm -> OK** 

#### Ask for the current gps position

If you want to know the gps position of your system you can send a simple sms with **gps**.
If the gps awake the next time and the gps tracking is active then you will receive a URL 
with the current gps position as an google request.

This URL can then easily be opened via your browsers in google and if everything works you 
will see the current location of the module on a Google map

    https://maps.google.com/maps?q=61.496052,23.7798"

#### Set some sms parameter

You can change the interval at which the system polls incoming SMS.
For this you can send i.e. the following command

**sms:15**

This change the interval to 15 seconds.
The response should be 

    sms:15 -> OK

#### Set some mqtt parameter

If you want to change the mqtt interval for sending data on moving or standing you can use the command sms
**mqtt:30:60**
This sets the interval on moving to 30 seconds and the interval on not moving to 30 seconds.
The response should be 

    mqtt:30:60 -> OK

### Change the response phone number

If you want to change the phone number to which the result should go then you can do this with:

**phone:123456789**

Then the new mobile phone number should receive the following result sms.

    phone:123456789 -> OK

#### Or send back the command list

If the system receives an invalid command then it sends back the list of commands:

    wrong command
    on
    off
    status
    psm[:off] - power saving mode
    gps[:15] - check every (sec)
    sms[:15] - check every (sec)
    mqtt[30:60] - (moving:standing (sec)
    phone:1234

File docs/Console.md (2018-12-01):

### Work with the console

With the console page you can monitor the activities of your system and send your 
own commands to the SIM808 module.

You can set the level of detail using the **Debug Active** option.

Note: To communicate with the SIM808 module this must be switched on

   Console Page

If you want to send your own AT commands to the SIM808 it is advisable to deactivate the 
SMS, GPS and MQTT functions under Settings during this time, otherwise they may interfere 
with your commands.

For details see

[**SIM800 AT commands**](https://www.elecrow.com/download/SIM800%20Series_AT%20Command%20Manual_V1.09.pdf)

[**SIM808 GPS AT commands**](https://cdn-shop.adafruit.com/datasheets/SIM808_GPS_Application_Note_V1.00.pdf)

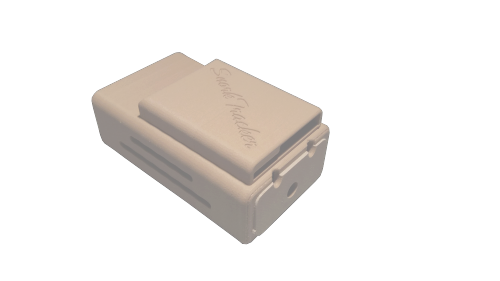
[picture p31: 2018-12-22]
images/origin/HousingWood.png

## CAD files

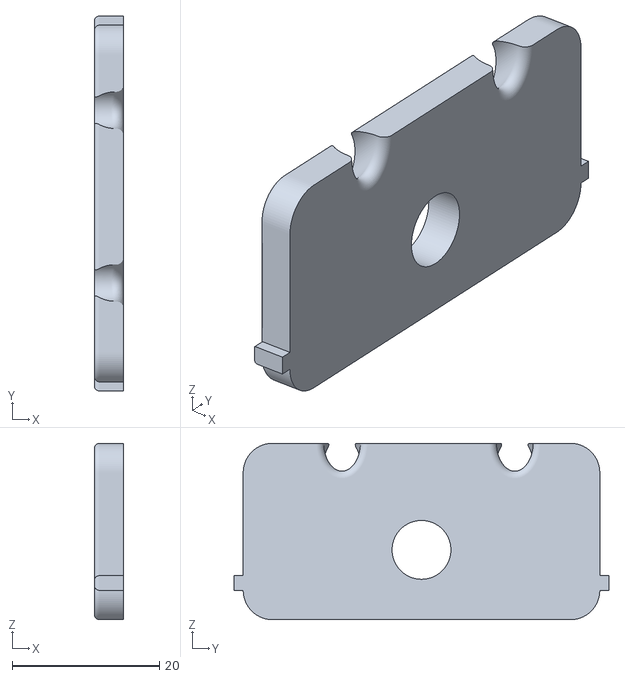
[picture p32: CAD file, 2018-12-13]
housing/Cap.stl
4.00 x 51.0 x 24.0

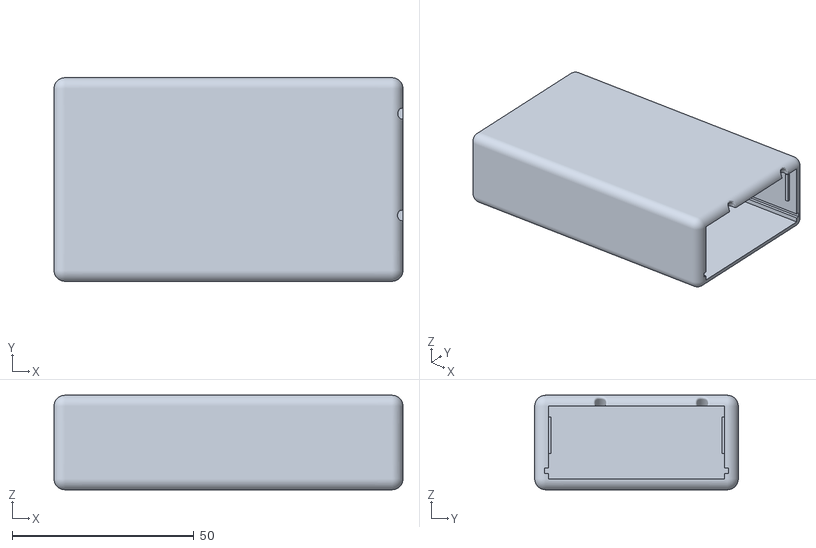
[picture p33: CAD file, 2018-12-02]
housing/Body.stl
96.0 x 56.0 x 26.0

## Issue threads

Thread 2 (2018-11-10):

fill the user manual

Bastelschlumpf, 2018-11-10:

Bastelschlumpf, 2018-11-25:
Fill missing
   Switch on or off the system
   Display system information
   Working with the console
   Firmware Update 'over the air'
   Restart the system

Closed 2018-12-02.

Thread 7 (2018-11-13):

Wrong values on BME280 sensor

Bastelschlumpf, 2018-11-13:
The values are to high

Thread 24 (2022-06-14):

Dismantling the system

BROU97, 2022-06-14:
--------------- CUT HERE FOR EXCEPTION DECODER ---------------

 ets Jan  8 2013,rst cause:2, boot mode:(3,6)

load 0x4010f000, len 3460, room 16
tail 4
chksum 0xcc
load 0x3fff20b8, len 40, room 4
tail 4
chksum 0xc9
csum 0xc9
v000592a0
~ld
1: Start SnorkTracker ...
1: MyGsmPower::begin
1: Failed to read options file
1: MyVoltage::begin

BROU97, 2022-06-14:
hello sir, I can't get started with the system for two days now.

please help me.

At first there was the problem of ''ConfiOverride.h'', I used ''config-override.h'' to solve the problem.
Now when it finishes the download this is what the map displays

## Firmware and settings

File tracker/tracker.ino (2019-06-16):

/*
   Copyright (C) 2018 SFini

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
   You should have received a copy of the GNU General Public License
   along with this program.  If not, see <http://www.gnu.org/licenses/>.
*/
/**
  * @file tracker.ino 
  *
  * Main file with setup() and loop() functions
  */


#include <SoftwareSerial.h>
#include <ArduinoOTA.h>
#include <FS.h>

#define SIM808_CONNECTED

#include "Config.h"
#define USE_CONFIG_OVERRIDE //!< Switch to use ConfigOverride
#ifdef USE_CONFIG_OVERRIDE
  #include "ConfigOverride.h"
#endif

#include "Utils.h"
#include "StringList.h"
#include "Gps.h"
#include "Options.h"
#include "Data.h"
#include "Voltage.h"
#include "DeepSleep.h"
#include "WebServer.h"
#include "GsmPower.h"
#include "GsmGps.h"
#include "SmsCmd.h"
#include "Mqtt.h"
#include "BME280.h"


#define     PIN_POWER     D3                                        //!< power on/off to DC-DC LM2596
#define     PIN_BME_GRND  D4                                        //!< Ground pin to the BME280 module
#define     BME_ADDRESS   0x77                                      //!< BME280 port address (Default 0x77, China 0x76)
#define     PIN_TX        D5                                        //!< Transmit-pin to the sim808 RX
#define     PIN_RX        D6                                        //!< Receive-pin to the sim808 TX
                                                                 
MyOptions   myOptions;                                              //!< The global options.
MyData      myData;                                                 //!< The global collected data.
MyVoltage   myVoltage(myOptions, myData);                           //!< Helper class for deep sleeps.
MyDeepSleep myDeepSleep(myOptions, myData);                         //!< Helper class for deep sleeps.
MyWebServer myWebServer(myOptions, myData);                         //!< The Webserver
MyBME280    myBME280(myOptions, myData, PIN_BME_GRND, BME_ADDRESS); //!< Helper class for the BME280 sensor communication.

#ifdef SIM808_CONNECTED
   MyGsmPower  myGsmPower(myData, PIN_POWER);                       //!< Helper class to switch on/off the sim808 power.
   MyGsmGps    myGsmGps(myOptions, myData, PIN_RX, PIN_TX);         //!< sim808 gsm/gps communication class.
   MySmsCmd    mySmsCmd(myGsmGps, myOptions, myData);               //!< sms controller class for the sms handling.
   MyMqtt      myMqtt(myGsmGps.gsmClient, myOptions, myData);       //!< Helper class for the mqtt communication via gsm.
#else                                                               //!< Helper class for the mqtt communication via wifi.
   MyMqtt      myMqtt(MyWebServer::server.wifiClient(), myOptions, myData); 
#endif                                                          

bool        gsmHasPower = false;                                    //!< Is the DC-DC modul switched on?
bool        isStarting  = false;                                    //!< Are we in a starting process?
bool        isStopping  = false;                                    //!< Are we in a stopping process?

/**
 * ***** IMPORTANT *****
 * It seems that the yield function of ESP does not feed the watch dog timer.
 * So we overwrite the yield() function here. If not the program crashed on some waits.
 * ***** IMPORTANT *****
 */
void yield(void)
{
   ESP.wdtFeed();
}

/** Overwritten Debug Function 
  * It logs all the debug calls to the console string-list
  * And call a refresh of the webserver for not blocking the system.
  */
void myDebugInfo(String info, bool fromWebserver, bool newline)
{
   static bool lastNewLine = true;
   
   if (newline || lastNewLine != newline) {
      String secs = String(secondsSincePowerOn()) + F(": ");

      myData.logInfos.addTail(secs + info);
      if (!lastNewLine) {
         Serial.println("");
      }
      Serial.println(secs + info);
   } else {
      String tmp = myData.logInfos.removeTail();

      Serial.print(tmp + info);
      myData.logInfos.addTail(tmp + info);
   }
   lastNewLine = newline;

   if (!fromWebserver) {
      myWebServer.handleClient();   
      myWebServer.handleClient();   
      myWebServer.handleClient();   
   } 
   delay(1);
   yield();
}

/** Overwritten delay loop for refreshing the webserver on waiting processes. */
void myDelayLoop()
{
   myWebServer.handleClient();   
   myWebServer.handleClient();   
   myWebServer.handleClient(); 
   delay(1);
   yield();
}

/** Returns the seconds since power up (not since last deep sleep). */
long secondsSincePowerOn()
{
   return myData.secondsSincePowerOn();
}

/** Main setup function. This is also called after every deep sleep. 
  * Do the initialization of every sub-component. */
void setup() 
{
   Serial.begin(115200); 
   delay(1000);

   MyDbg(F("Start SnorkTracker ..."));

#ifdef SIM808_CONNECTED
   myGsmPower.begin();
#endif
   SPIFFS.begin();
   myOptions.load();
   myVoltage.begin();

   // Back to deep sleep?
   myDeepSleep.begin();

   // no deep sleep!
   myWebServer.begin();
   myMqtt.begin();
#ifdef SIM808_CONNECTED
   mySmsCmd.begin();
#endif
   myBME280.begin();
}

/** Main loop function.
  * Read the power supply voltage.
  * Checks for console inputs and send them to the SIM808 modul.
  * Checks for OTA activities.
  * Start or stop the gsm and/or gps activities.
  * Check for receiving sms and process them.
  * Checks the gps and send the overall information to a mqtt server if needed.
  * Starts the deep sleep mode if needed.
  */
void loop() 
{
   myVoltage.readVoltage();
   myBME280.readValues();

   myWebServer.handleClient();
   
   if (myData.isOtaActive) {
      ArduinoOTA.handle();    
   }

#ifndef SIM808_CONNECTED
   if (myOptions.isMqttEnabled) {
      myMqtt.handleClient();
   }

   if (!myMqtt.waitingForMqtt()) {
      if (myDeepSleep.haveToSleep()) {
         WiFi.disconnect();
         WiFi.mode(WIFI_OFF);
         yield();
         myDeepSleep.sleep();
      }
   }
#else
   if (!myData.consoleCmds.isEmpty()) {
      String cmd = myData.consoleCmds.removeHead();

      myGsmGps.sendAT(cmd);
   }

   // Starting gsm ?
   if (myOptions.powerOn && !gsmHasPower) {
      if (!isStarting && !isStopping) {
         isStarting = true;
         myGsmPower.on(); 
         gsmHasPower = true;
         if (!myGsmGps.begin()) {
            myGsmGps.stop();
            myGsmPower.off();
            gsmHasPower = false;
         }
         isStarting = false;
      }
   }

   // Stopping gsm ?
   if (!myOptions.powerOn && gsmHasPower) {
      if (!isStarting && !isStopping) {
         isStopping = true;
         myGsmGps.stop();
         myGsmPower.off();
         gsmHasPower = false;
         isStopping  = false;   
      }
   }

   // Do gsm processing.
   if (gsmHasPower && !isStarting && !isStopping) {
      myGsmGps.handleClient();

      // No sms or mqtt if we are waiting for a gps position.
      // Otherwise we are sending invalid gps values.
      if (!myGsmGps.waitingForGps()) {
         if (myOptions.isSmsEnabled) {
            mySmsCmd.handleClient();
         }
         if (myOptions.isMqttEnabled) {
            myMqtt.handleClient();
         }
      }
   }

   // Deep Sleep?
   // (No deep sleep if we are waiting for a valid gps position).
   if (!myGsmGps.waitingForGps() && !myMqtt.waitingForMqtt()) {
      if (myDeepSleep.haveToSleep()) {
         if (myData.isGsmActive) {
            myGsmGps.stop();
         }
         myGsmPower.off();
         WiFi.disconnect();
         WiFi.mode(WIFI_OFF);
         yield();
         myDeepSleep.sleep();
      }
   }

#endif

   yield();
   delay(10); 
}

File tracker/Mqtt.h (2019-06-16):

/*
   Copyright (C) 2018 SFini

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
   You should have received a copy of the GNU General Public License
   along with this program.  If not, see <http://www.gnu.org/licenses/>.
*/
/**
  * @file Mqtt.h
  *
  * Communication with an MQTT server.
  */


#include <PubSubClient.h>

#define topic_deep_sleep             "/DeepSleep"              //!< Deep sleep on/off

#define topic_voltage                "/Voltage"                //!< Power supply voltage
#define topic_mAh                    "/mAh"                    //!< Power consumption
#define topic_mAhLowPower            "/mAhLowPower"            //!< Power consumption in low power
#define topic_alive                  "/Alive"                  //!< Alive time in sec
#define topic_rssi                   "/RSSI"                   //!< Wifi conection quality

#define topic_power_on               "/PowerOn"                //!< switch power on/off
#define topic_gps_enabled            "/GpsEnabled"             //!< switch gps on/off
#define topic_send_on_move_every     "/SendOnMoveEverySec"     //!< mqtt send interval on moving
#define topic_send_on_non_move_every "/SendOnNonMoveEverySec"  //!< mqtt sending interval on non moving
#define topic_send_every             "/SendEverySec"           //!< mqtt sending interval

#define topic_temperature            "/BME280/Temperature"     //!< Temperature
#define topic_humidity               "/BME280/Humidity"        //!< Humidity
#define topic_pressure               "/BME280/Pressure"        //!< Pressure

#define topic_signal_quality         "/Gsm/SignalQuality"      //!< Signal quality
#define topic_batt_level             "/Gsm/BattLevel"          //!< Battery level of the gsm modul
#define topic_batt_volt              "/Gsm/BattVolt"           //!< Battery volt of the gsm modul

#define topic_gps                    "/Gps"                    //!< Gps longitude, latitude, altitude, moving speed
#define topic_gps_distance           "/GpsDistance"            //!< Gps distance to last position         

/**
  * MQTT client for sending the collected data to a MQTT server
  */
class MyMqtt : protected PubSubClient
{
protected:
   static MyOptions *g_myOptions;   //!< Static option pointer for the callback function.

public:
   static void mqttCallback(char* topic, byte* payload, unsigned int len);
   
protected:
   MyOptions &myOptions;            //!< Reference to the options. 
   MyData    &myData;               //!< Reference to the data.
   bool       publishInProgress;    //!< Are we publishing right now.

protected:
   bool mySubscribe(String subTopic);
   bool myPublish(String subTopic, String value);

public:
   MyMqtt(Client &client, MyOptions &options, MyData &data);
   ~MyMqtt();
   
   bool begin();
   void handleClient();
   
   bool waitingForMqtt();
};

/* ******************************************** */

/** Constructor/Destructor */
MyMqtt::MyMqtt(Client &client, MyOptions &options, MyData &data)
   : PubSubClient(client)
   , myOptions(options)
   , myData(data)
   , publishInProgress(false)
{
   g_myOptions = &options;
}
MyMqtt::~MyMqtt()
{
   g_myOptions = NULL;
}

/** Helper function to subscrbe on mqtt 
 *  It put the mqttName and id from options before the topic.
*/
bool MyMqtt::mySubscribe(String subTopic)
{
   if (!myData.isGsmActive) {
      return false;
   }

   String topic;

   topic = myOptions.mqttName + F("/") + myOptions.mqttId + subTopic;
   MyDbg((String) F("MyMqtt::subscribe: [") + topic + F("]"), true);
   return PubSubClient::subscribe(topic.c_str());
}

/** Helper function to publish on mqtt 
 *  It put the mqttName from optione before the topic.
*/
bool MyMqtt::myPublish(String subTopic, String value)
{
   if (!myData.isGsmActive) {
      return false;
   }

   bool ret = false;

   if (value.length() > 0) {
      String topic;

      topic = myOptions.mqttName + F("/") + myOptions.mqttId + subTopic;
      MyDbg((String) F("MyMqtt::publish: [") + topic + F("]=[") + value + F("]"), true);
      ret = PubSubClient::publish(topic.c_str(), value.c_str(), true);
   }
   return ret;
}

/** Check if we have to wait for sending mqtt data. */
bool MyMqtt::waitingForMqtt()
{
   if (!myData.isGsmActive) {
      return false;
   }
   if (publishInProgress) {
      return true;
   }
   if (myData.isMoving) {
      return secondsElapsed(myData.rtcData.lastMqttPublishSec, myOptions.mqttSendOnMoveEverySec);
   } else {
      return secondsElapsed(myData.rtcData.lastMqttPublishSec, myOptions.mqttSendOnNonMoveEverySec);
   }
   return false;
}

/** Sets the MQTT server settings */
bool MyMqtt::begin()
{
   MyDbg(F("MQTT:begin"), true);
   PubSubClient::setServer(myOptions.mqttServer.c_str(), myOptions.mqttPort);
   PubSubClient::setCallback(mqttCallback);
   return true;
}

/** Connect To the MQTT server and send the data when the time is right. */
void MyMqtt::handleClient()
{
   if (!myData.isGsmActive) {
      return;
   }

   bool send = false;

   if (myData.isMoving) {
      send = secondsElapsed(myData.rtcData.lastMqttPublishSec, myOptions.mqttSendOnMoveEverySec);
   } else {
      send = secondsElapsed(myData.rtcData.lastMqttPublishSec, myOptions.mqttSendOnNonMoveEverySec);
   }
   if (send && !publishInProgress) {
      publishInProgress = true;
      if (!PubSubClient::connected()) {
         for (int i = 0; !PubSubClient::connected() && i < 5; i++) {  
            MyDbg(F("Attempting MQTT connection..."), true);
            if (PubSubClient::connect(myOptions.mqttName.c_str(), myOptions.mqttUser.c_str(), myOptions.mqttPassword.c_str())) {  
               // mySubscribe(topic_deep_sleep);
               // mySubscribe(topic_power_on);
#ifdef SIM808_CONNECTED
               // mySubscribe(topic_gps_enabled);
               // mySubscribe(topic_send_on_move_every);
               // mySubscribe(topic_send_on_non_move_every);
#endif
               MyDbg(F(" connected"), true);
            } else {  
               MyDbg((String) F("   Mqtt failed, rc = ") + String(PubSubClient::state()), true);
               MyDbg(F(" Try again in 5 seconds"), true);
               MyDelay(5000);
               MyDbg(F("."), true, false);
            }  
         }  
      }
      if (PubSubClient::connected()) {
         char gpsJson[255];

         MyDbg(F("Attempting MQTT publishing"), true);
         myPublish(topic_voltage,     String(myData.voltage, 2));
         myPublish(topic_mAh,         String(myData.getPowerConsumption()));
         myPublish(topic_mAhLowPower, String(myData.getLowPowerPowerConsumption()));
         myPublish(topic_alive,       formatInterval(myData.getActiveTimeSec()));
#ifndef SIM808_CONNECTED
         myPublish(topic_rssi,        WifiGetRssiAsQuality(WiFi.RSSI()));
#endif
         myPublish(topic_temperature, String(myData.temperature));
         myPublish(topic_humidity,    String(myData.humidity));
         myPublish(topic_pressure,    String(myData.pressure));
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

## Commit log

2018-11-10 First version
    [Esp8266Sim808.fzz]
2018-11-10 circuit images in doxgen
2018-11-13 Case sensitive DoxyGen url
2018-11-15 Wlan was not working after deep slep.
    [tracker.ino]
2018-11-15 WLAN rtc und deep sleep problem info
2018-11-16 Complete overhaul of the deep sleep and active time counting.
    I measure the power consumption and now we can show the overall power consumption on the information page.
    At the moment we have to show the passwords in clear text because the browser overwritten the first password
    with the second one with the stupid autocomplete.
2018-11-17 On the information page we show now the
    power consumption of the modul and
    the power consumption on low power.
2018-11-17 sms command for switch on/off power saving mode.
2018-11-18 sms command psm (power save mode) case insensitive
2018-11-19 * If we are waiting for a gps position then the deep sleep is disabled. *
    remove deepSleepLocked.
    remove send sms on call. It does not work properly.
    myDelay is now MyDelay
    [BME280.h, Mqtt.h]
2018-11-20 Send also mAh and mAh on low power to mqtt server.
2018-11-22 I have some mqtt crashes, so I first simplify the calling function.
    [Mqtt.h]
2018-11-23 SerialOu: Helper class for debugging via Serial.println
2018-11-23 ATTENTION: It seems that the yield function of ESP does not feed the watch dog timer.
    So we do it here. If not the program crashed on some waits.
    [tracker.ino]
2018-11-23 We can activate our yield delay if we have the watch dog timer resets.
2018-11-24 Bug: No debug messages visible
    [tracker.ino]
2018-11-24 Enable deep sleep only if the module is switched on.
2018-11-24 Rename secondsElapsed() to secondsElapsedAndUpdate() and
    new function secondsElapsed() only for checking.
    Switch to enable/disable the sms functionality.
    No deep sleep if we have to send mqtt.
2018-12-01 Housing Prototype
2018-12-02 To simplify I remove the isGsmEnabled flag. Power on is enough.
2018-12-02 3D housing model for 3D printing
    [Body.stl, Cap.stl, GpsBox.stl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]
2018-12-02 Housing wrong image
2018-12-06 New housing version
    [Cap.stl, GpsBox.stl, GsmBox.stl]
2018-12-13 Better version for 3D printing
    [Cap.stl]
2018-12-16 Added the 12V cigar lighter power supply.
2018-12-16 The first 3D printed version in black
2018-12-22 First Circuit then housing
2018-12-22 Good Wood Housing
2018-12-28 No switch off when gsm could not established. Lets try again
2018-12-30 Using Wemos PIN define instead of origin PIN Number
2018-12-31 BME280_POWER pin is in fact a ground pin.
2018-12-31 Reset environment values if data is invalid.
    [BME280.h]
2019-01-01 Adding a temperature correction for the BME280
    And set the SCL and SDA pin to open state to safe a little power.
    [BME280.h]
2019-02-17 - New option for setting the GPRS user and password.
    - Store the last gps coordinates now in the rtc deep sleep memory
    - Rearrange some helper functions time/date
    - No reset of the alst gps while scanning for new location
    [Mqtt.h]
2019-03-07 To be sure that the analog pin is on input mode.
2019-03-07 - Voltage with two digits precision
    - Alive time as interval
2019-03-07 rename gsmPower to powerOn
2019-06-16 Problems with deep sleep and power on.
    [Mqtt.h]
2019-07-12 Add SnorkView sample

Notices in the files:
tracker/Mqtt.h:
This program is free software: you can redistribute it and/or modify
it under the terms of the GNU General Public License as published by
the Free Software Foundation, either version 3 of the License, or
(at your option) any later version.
